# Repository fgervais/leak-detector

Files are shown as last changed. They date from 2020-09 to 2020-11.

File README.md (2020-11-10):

# TinyPICO/ESP32 Leak Detector

Detect leaks, trigger an alarm and send a notification to your phone.

It can be used to save your wood flooring for example as wiping the water off
a couple minutes sooner can make a difference.

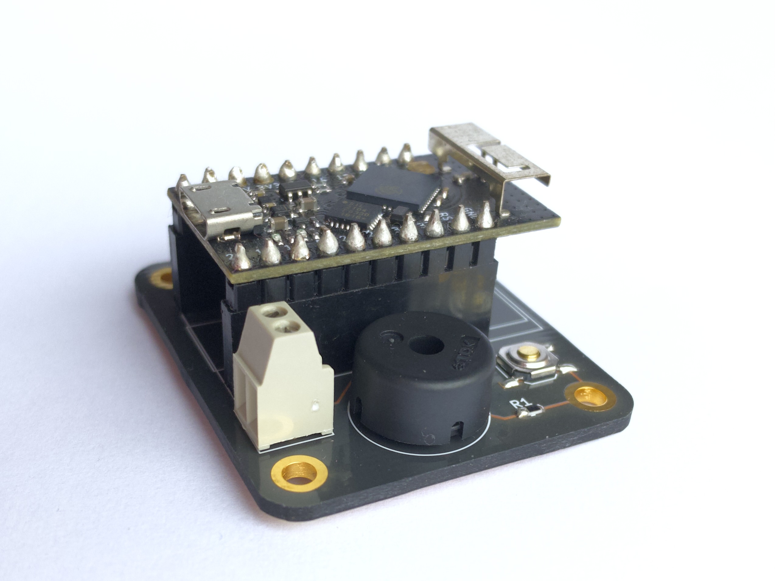
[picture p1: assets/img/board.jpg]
TinyPICO on the motherboard


## Complete System

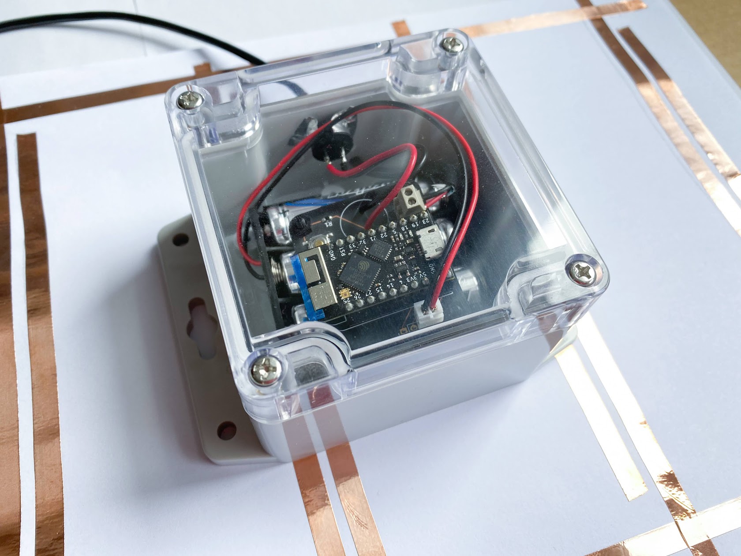
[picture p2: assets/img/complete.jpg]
Complete


## Detection Electrode

To detect a leak, the idea is that water need to bridge the 2 screw terminal
leads.

On my end what I'm doing for this project is using copper tape traces that run
close to each other. Basically the same technique used by some types of user
buttons but bigger.

Those copper traces are on a sheet of paper allowing even a single drop of water
to have quite a wide coverage. This way really little water is required to get
a detection even in the worse case.

## Battery Power

With the first revision of this project, I went with the micropython version
shipped with the TinyPICO and a single 18650 cell. I was aiming to get a
3 years run between recharge but I only got 37 weeks.

Further investigation showed that the majority of the power was used by the
touch detection as the default touch sensor parameters are quite aggressive.

To fix this, I had to expose more of the touch sensor API as shown here:
https://github.com/micropython/micropython/pull/6408. With this I was able to
change the touch sensor polling rate from 37 Hz to about 2 Hz. I also reduced
the time it stays on, looking for a touch.

With these changes in place, the limiting factor for the battery life seemed to
be the self-discharge of the li-ion cell. To mitigate that I changed the 18650
cell by 3 AA Energizer® Ultimate Lithium batteries. These are advertised to
have a really low self discharge and I'm hoping they will perform as so.

## Blynk

The detector gets controlled by a [Blynk](https://blynk.io/) app.

In the Blynk app you see a beacon that is sent by the device every week so you
know the device is still alive. The beacon is dual purpose as the data is the
battery voltage capped to 3.7v.

In the screenshot you can see the li-ion battery discharging to full to about
dead in 37 weeks.

Note that this was before changing the battery type and [optimizing](https://github.com/fgervais/leak-detector/commit/07dddd6354a1dfdce8fd6b8dc646baeb9ef110fd)
the touch sensor power consumption. The battery should last much longer now.

Blynk Project | Blynk Project Clone QR
:-------------------------:|:-------------------------:
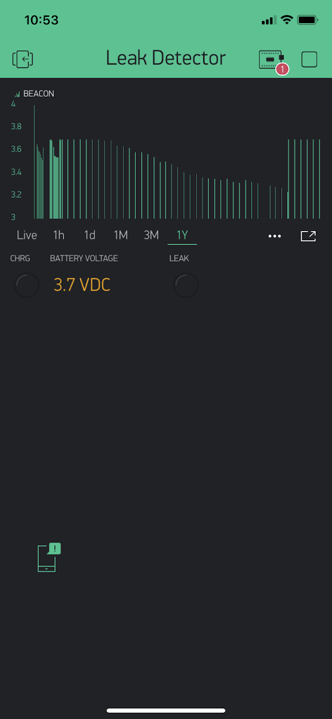
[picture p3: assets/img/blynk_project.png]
Blynk Project
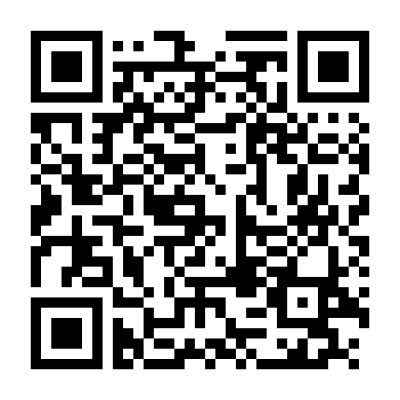
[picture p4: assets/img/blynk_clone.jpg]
Blynk Project QR
  |  

The QR code should give you a complete copy of my project if scanned in the
Blynk app.

# Hardware

The board (rev1) and the BOM are accessible here:

- https://oshpark.com/shared_projects/Uk5klm7L
- https://www.digikey.ca/short/z0c01q

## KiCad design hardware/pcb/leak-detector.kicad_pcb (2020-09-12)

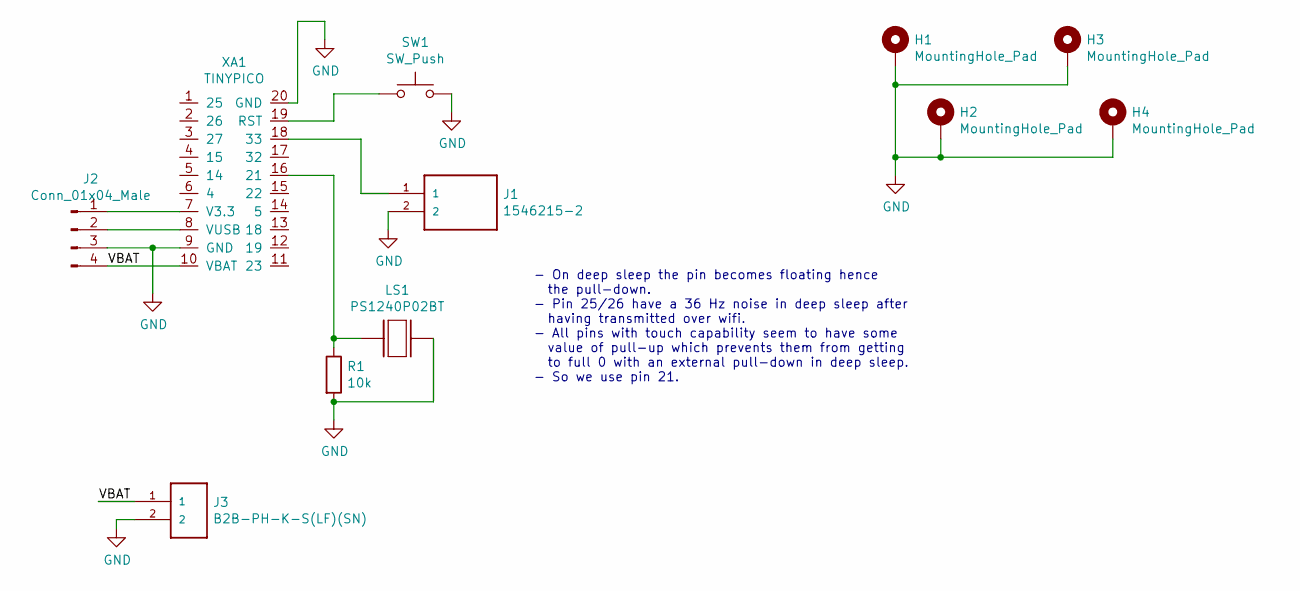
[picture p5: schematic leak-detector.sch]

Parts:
H1, H2, H3, H4: MountingHole_Pad; MountingHole_2.7mm_M2.5_ISO7380_Pad
J1: 1546215-2; TE_1546215-2
J2: Conn_01x04_Male; PinHeader_1x04_P2.54mm_Vertical
J3: B2B-PH-K-S(LF)(SN); JST_B2B-PH-K-S(LF)(SN)
LS1: PS1240P02BT; XDCR_PS1240P02BT
R1: 10k; R_0603_1608Metric_Pad1.05x0.95mm_HandSolder
SW1: SW_Push; SW_SPST_TL3342
XA1: TINYPICO

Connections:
/VBAT: J2.4, J3.1, XA1.10 (VBAT)
GND: H1.1, H2.1, H3.1, H4.1, J1.2, J2.3, J3.2, LS1.2, R1.2, SW1.2, XA1.9 (GND), XA1.20 (GND)
unnamed: J1.1, XA1.18 (33)
unnamed: J2.1, XA1.7 (V3.3)
unnamed: J2.2, XA1.8 (VUSB)
unnamed: LS1.1, R1.1, XA1.16 (21)
unnamed: SW1.1, XA1.19 (RST)

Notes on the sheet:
- On deep sleep the pin becomes floating hence the pull-down. - Pin 25/26 have a 36 Hz noise in deep sleep after having transmitted over wifi. - All pins with touch capability seem to have some value of pull-up which prevents them from getting to full 0 with an external pull-down in deep sleep. - S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

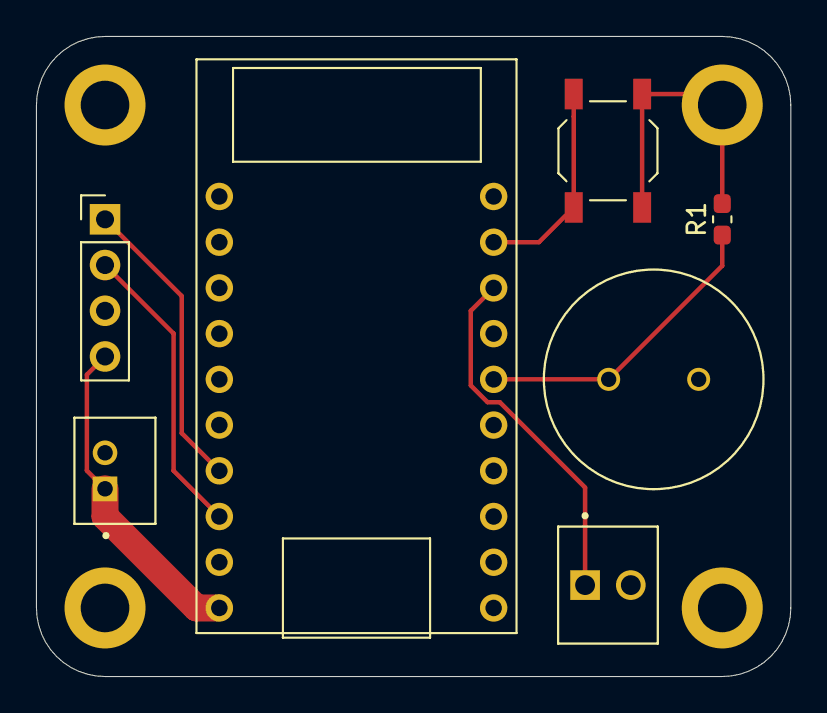
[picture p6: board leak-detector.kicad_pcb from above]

Board: 2 copper layers, 41.9 x 35.6 mm, 11 parts (0 on the bottom side), 7 nets.

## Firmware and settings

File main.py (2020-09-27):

import network
import time
import tinypico as TinyPICO
import micropython
import esp32
import blynklib
import secret
import machine

from machine import Pin, PWM, ADC, TouchPad, RTC


BEACON_VPIN = 1
LEAK_LED_VPIN = 2
CHARGING_VPIN = 3
LEAK_VAL_VPIN = 4

LEAK_CAP_THRESHOLD = 10

LEAK_TOUCHPAD_PIN = 33
BUZZER_PIN = 21


wlan = network.WLAN(network.STA_IF)
def connect():
    wlan.active(True)
    if not wlan.isconnected():
        print('connecting to network...')
        wlan.connect(secret.ESSID, secret.PSK)
        while not wlan.isconnected():
            time.sleep(1)
    print('network config:', wlan.ifconfig())

def usb_connected():
    return (TinyPICO.get_battery_voltage() == 3.7)


class Device:
    def __init__(self, blynk, buzzer_pwm, wifi_connect_function, leak_pad):
        self.blynk = blynk
        self.buzzer_pwm = buzzer_pwm
        self.wifi_connect_function = wifi_connect_function
        self.leak_pad = leak_pad

        self.connected = False

    def connect(self):
        if not self.connected:
            self.wifi_connect_function()
            self.blynk.connect()
            self.connected = True

    def blynk_virtual_write(self, vpin, value):
        self.connect()

        self.blynk.virtual_write(vpin, value)
        self.blynk.run()

    def blynk_notify(self, msg):
        self.connect()

        self.blynk.notify(msg);
        self.blynk.run()

    def beacon(self):
        self.blynk_virtual_write(
            BEACON_VPIN,
            TinyPICO.get_battery_voltage())

    def alarm(self, seconds):
        start_time = time.time()
        while time.time() < start_time + seconds:
            for i in range(3):
                self.buzzer_pwm.duty(512)
                time.sleep(0.25)
                self.buzzer_pwm.duty(0)
                time.sleep(0.25)

    @property
    def leak_led(self):
        return False

    @leak_led.setter
    def leak_led(self, state):
        self.blynk_virtual_write(LEAK_LED_VPIN, 255 if state else 0)

    @property
    def charging(self):
        return False

    @charging.setter
    def charging(self, state):
        self.blynk_virtual_write(CHARGING_VPIN, 255 if state else 0)

    def leak_detected(self):
        self.leak_led = True
        self.blynk_notify("A leak has been detected!");

    def teardown(self):
        if self.connected:
            self.blynk.disconnect()

    def is_leak(self):
        try:
            if self.leak_pad.read() < LEAK_CAP_THRESHOLD:
                return True
        except:
            return True

        return False

    def show_leak_cap_value(self):
        try:
            value = self.leak_pad.read()
        except:
            value = 0

        print("Leak capacitance: " + str(value))
        self.blynk_virtual_write(LEAK_VAL_VPIN, value)


initial_buzzer_duty = 0
if machine.reset_cause() == machine.PWRON_RESET:
    initial_buzzer_duty = 512

buzzer = PWM(Pin(BUZZER_PIN), freq=4000, duty=initial_buzzer_duty)
time.sleep(0.05)
buzzer.duty(0)

leak_detect_pad = TouchPad(Pin(LEAK_TOUCHPAD_PIN))
leak_detect_pad.config(LEAK_CAP_THRESHOLD)
print("Slowing down touch sensor measurement rate")
esp32.set_touch_sensor_measurement_time(
    0xffff, # 2.28885 Hz
    0x1fff) # 1.02388 ms

rtc = RTC()
print("RTC memory: {}".format(rtc.memory()))
error_reported = True if rtc.memory() else False

blynk = blynklib.Blynk(secret.BLYNK_AUTH, log=print)
dishwasher = Device(blynk, buzzer, connect, leak_detect_pad)

if not dishwasher.is_leak():
    print("There is no leak")
    dishwasher.leak_led = False
    dishwasher.beacon()
    # The touchpad reading gets lower when wifi is activated so it's possible
    # that we get here (there is no leak) but still that the capacitance
    # shown below is below LEAK_CAP_THRESHOLD since here we sent a beacon
    # hence we are connected to wifi.
    # It doesn't affect a real leak since a leak bottoms out the capacitance
    # to 0.
    dishwasher.show_leak_cap_value()
    esp32.wake_on_touch(True)
    sleep_time = 7 * 24 * 60 * 60 * 1000 # 1 week

    print("Let say we are not charging")
    dishwasher.charging = False

else:
    print("A leak has been detected!")
    if not error_reported:
        dishwasher.leak_detected()
        dishwasher.show_leak_cap_value()
        rtc.memory(b'\x01')

    # If the error was already reported, we should not be connected to wifi here.
    # This is so we can go to sleep and wakeup and beep again without wasting
    # energy on wifi for each loop.

    dishwasher.alarm(60)

    esp32.wake_on_touch(False)
    sleep_time = 0 # forever


dishwasher.teardown()

if wlan.isconnected():
    wlan.disconnect()
    while wlan.isconnected():
        time.sleep(1)

print("Going to sleep")
TinyPICO.go_deepsleep(sleep_time)

print("not reached")

while True:
    pass

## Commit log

2019-11-02 Report a leak when detected
    [main.py]
2019-11-09 Print a smiley face on detection
2019-11-12 When charging wake up every 5 minutes
2019-11-12 Add the charging led
2019-11-12 Show leak capacitance on boot
    [main.py]
2019-11-14 Report the leak once
    [main.py]
2019-11-14 Give connection management to Device
2019-11-24 Battery charging workaround
2019-11-24 When charging, wake-up every 30 minutes
2019-11-24 Little beep only on power on
2019-11-25 Only check if battery is charging if there is no leak
    [main.py]
2019-12-01 On leak, alarm 60s, sleep forever
    [main.py]
2019-12-04 Remove the buggy charge indicator
    [main.py]
2020-08-31 Use pin 27 for the buzzer
    It seem that this pin doesn't have the 36 Hz noise when in deep sleep.
    [main.py]
2020-09-05 Use pin 21 for the buzzer
    The pin 27 seems to have some value of pull-up and so can't be completely
    pulled down in deep sleep resulting in some current loss.
    [main.py]
2020-09-05 Reduce the current used by the touch sensor
    Reduced by a factor of 64 (16*4).
2020-09-12 Add pcb rev 2
    This version has the JST-PH battery connector.
    [leak-detector.kicad_pcb, leak-detector.sch]
2020-09-27 Change leak threshold to 10
    [main.py]
2020-09-27 Fix board image extension
2020-10-21 Change board picture
